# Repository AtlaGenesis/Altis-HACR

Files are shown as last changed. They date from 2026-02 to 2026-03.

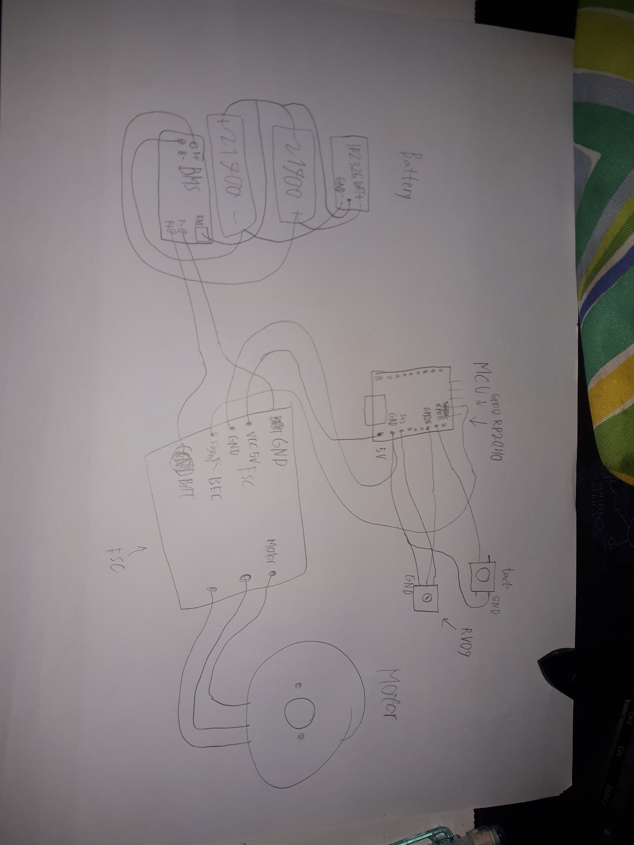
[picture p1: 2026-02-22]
Altis HACR/Wiring Diagram .jpg

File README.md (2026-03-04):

# Altis-HACR
A Handheld Fan designed for long and everlasting battery life, smooth airflow, and Compact Ergonomic design ready to accompany you in hot wheather.

# Elegant Design
Altis HACR
(rendered in fusion)
Gemini_Generated_Image_vhq5ehvhq5ehvhq5
(this one is AI-Generated only for visual effects, Don't use for ads)

# Usage instructions:
1. Position the fan so that you see the side with the fan blade furthest away from you.
2. Turn the knob all the way to the left
3. Press the button for 1 second
4. Slowly turn the knob to the right to adjust the wind speed, Hold the fan at 20-30cm distance from your face, to ensure air spreads across your face for maximum cooling and comfort
5. When you're done using, or that the device turned off, charge the device with a USB C cable, you can use your phone charger if it supports USB C
6. When it is charging, the LED indicator will turn red, when the battery is full, it will turn blue and will automatically stop charging

# Safety Features:
- It is designed with a shroud
- You can adjust the speed with a knob, allowing for smooth speed control suited for any situations
- It has an integrated battery protection system, preventing thermal runaways when an electrical error occured, and ensuring the batteries are not overcharged, and preventing the battery to reach 0% fully, as it can permanently damage the batteries
- Uses 2 Litium Ion batteries for higher energy density, safer discharge, and longer cycle life than Li-Po batteries
- The motor is a Brushless DC motor, allowing it to run faster, consumes lower power, and can operate comfortable for hours without overheating

# Wiring Diagram (sorry if paper)


# 3D printing material:

>ASA or stronger, Heated Bed, Enclosure, No Fan, Supports, Slow printing speed.
1. Body (Duct, Handle)
  - 25% Infill, Gyroid.
  - 6 - 8 Walls or Perimeter
  - White ASA
  - 0.12mm - 0.2mm Layer height, 0.4mm Nozzle
2. Fan Blade
  - 100% Infill
  - Walls or Perimeter set to MAX (MUST BE SOLID, 999 for most)
  - 0.12mm Layer Height, 0.4mm nozzle
  - Black ASA

>PETG, normal printing, little to no supports.
1. Fan Grill (PETG)
  - 100% Infill
  - Black PETG
  - 0.2mm / 0.4mm Layer height, 0.4mm Nozzle
  - 99 Walls or Perimeter
2. Knob (can be TPU)
  - 10% Infill
  - Black
  - 0.2mm-0.4mm Layer Height

# Why I made it
To be honest, it all started in 2025 of december when *I see these overpriced handheld fans on online shops, and wanted to compete with them*, then I bought a 15krpm rs280, and tested it with a toy fan blade, it was blowing my hair, so I thought: "why not make a cheaper one than theirs, but have better stuffs?"
and then I go to Blender and made it, I wasted my time, I discovered that DC motors sucks at long term use, so i abandoned the project, then I have an idea to make it using a PC axial fan, I did make it with my own money, I got discounted, I used it to chill in class, then I wanted to make a cleaner version, using those 100krpm edf turbo jet fan or something, those are inrunners, and... I figured out those aren't the best, cuz I know that it's impractical to have like 15 mins of runtime on 2 batteries..., so I made this! I calculated the rpm, tip speed, diameter, pitch, trying out fusion, trying out "parametric fan blade generator", then I dumped the generator, so I modified a pc fan blade design, and fit it into the motor (according to the motor desc), I made all of the stuffs (duct, handle, stator blades, etc) all without a reference, only a glimpse of what I imagined it would be like, so now I'm here, I really hope this would be my milestone in engineering, since I started making electronics in late october 2025, and I just discovered Hack Club back in December from an Instagram reel. 

# Special? 
I don't know, but after thinking for a while, I think it has some properties that are worth mentioning.
 1. Design
  The design is actually quite simple outside, but, it is not just a random duct, when you look closely into the cad, you'll see some hidden designs that you probably haven't seen before:
   

On the right side of the image, you can see a slight bell mouth shape inside, it's there to increase the air intake capability and also reducing turbulence, because the air can flow along the surfaces of the duct (That's why 0.12mm layer height is important!!!). And on the left side it's got a slight converging shape, to increase air velocity, and diverging to increase air spread, the small values of these shapes are choosen to maintain power efficiency and symmetry while also giving the effect it's intended to.



This picture shows the dimensions of the fan, these dimensions are calculated for maximum visual weight balance and comfort, 125mm long handle ensures it's not too long nor too short for your hand to grip, the fan diameter is chosen at 50mm for a balance of efficiency and portability, the 60mm duct diameter to 90mm centered duct lenght makes even better visual weight and symmetry, and the 2:1 handle to duct length and diameter also makes it perfectly balanced, for a very pleasing appearance.

# BOM
- 1x 1806 1700kv
https://shopee.co.id/Motor-Brushless-2s-3s-7.4V-12V-1806-1700KV-RC-Pesawat-i.165138131.40252534787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
- 
- 2x 21700 EVE 50E
https://shopee.co.id/Baterai-li-ion-3-7v-EVE-INR21700-50E-inr-21700-5000-mah-5-Ah-BARU-NEW-(5c-REAL-Grade-A-)-baterai-untuk-kendaraan-listrik-plts-alat-elektronik-la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
- 
- 1x BMS 2s 8A
https://shopee.co.id/BMS-2S-8A-8V-7.4V-8.4V-Baterai-Li-ion-Lithium-18650-Charger-Module-STANDAR-i.53753550.1999845549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
-
- 1x ESC BLHELI 12A BEC 5v 1A 2-3
https://shopee.co.id/BLHeli-12A-Mini-Brushless-Motor-ESC-BLHeli-14.2-2-3S-For-160-250-Multirotor-i.30918253.2840670835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
-
- 1x 10k potentiometer RV09 style
https://shopee.co.id/potensiometer-potentiometer-potensio-10k-rv09-12.5mm-RV-09-10-K-i.18663910.18844315772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
-
- 1x Tact switch 12x12x8mm
https://shopee.co.id/Tactile-Tact-Switch-Saklar-Push-On-Button-12*12mm-12x12mm-12x12-12*12-i.226801552.21733787099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
-
- 1x RP2040 Zero Raspberry Pi Pico
https://shopee.co.id/Raspberry-Pi-Pico-RP2040-Zero-Microcontroller-i.40647041.57550656215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
-
- 1x IP2326 2-3S charger module
https://shopee.co.id/IP2326-Step-Up-Battery-18650-Charger-Charging-2S-3S-BMS-With-Balance-1.5A-15Watt-Type-C-Battery-Charging-i.915347685.26127899926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
-
- 2x M2x8 screws rounded head
 https://shopee.co.id/Baut-JP-M2x8-Stainless-304-Phillips-Head-Screw-M2*8-Sekrup-2mm-x-8mm-M2-Obeng-Plus-SS304-i.96037146.24243396278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
-
- 2x M2x14 screws rounded head
 https://shopee.co.id/14mm-Baut-M2x14mm-M2-Phillips-Pan-Head-304-Stainless-Steel-i.76522437.25956472752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
-
- 6x M2x5 screws rounded head
https://shopee.co.id/Baut-JP-M2x5-Stainless-304-Phillips-Head-Screw-M2*5-Sekrup-2mm-x-5mm-M2-Obeng-Plus-SS304-i.96037146.27881616446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
-
- 8x M2x4x5 brass heat inserts
 https://shopee.co.id/Spiral-Brass-Nut-Insert-Spiral-brass-knur-insert-M2-M3-M4-(HARGA-PER-10PCS)-i.22308752.24463664962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

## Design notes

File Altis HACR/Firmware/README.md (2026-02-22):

# RP2040 ESC PWM Controller

## Wiring
- GIO12 → ESC signal
- GPIO15 → Button → GND
- GPIO26 → Pot wiper
- 3V3 → Pot
- GND → common ground

## Build
```bash
mkdir build
cd build
cmake ..
make

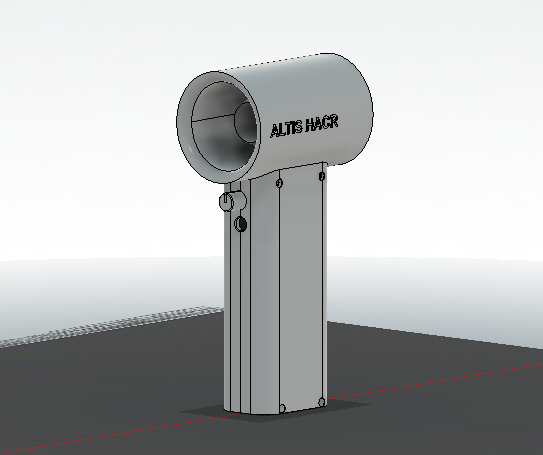
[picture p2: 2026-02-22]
Altis HACR/3D Models/View.png

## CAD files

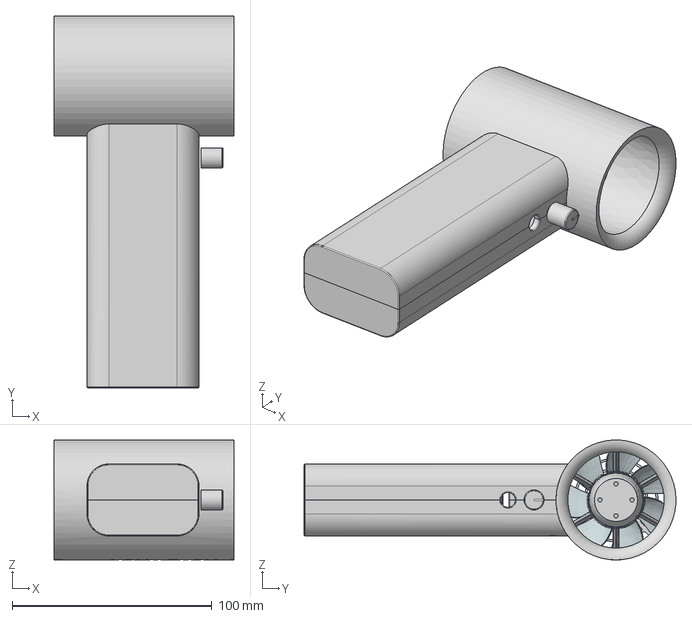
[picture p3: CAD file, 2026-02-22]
Altis HACR/3D Models/Altis HACR iterating.step
90.0 x 186.0 x 59.9 mm

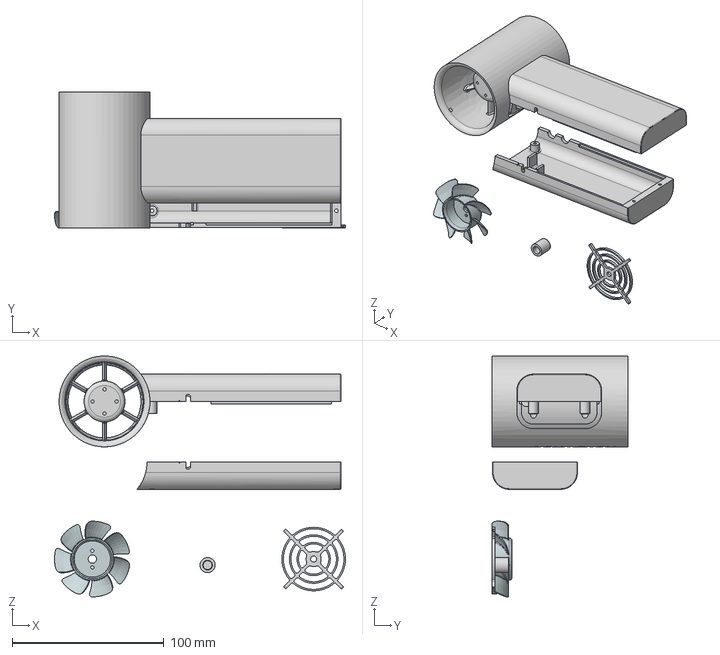
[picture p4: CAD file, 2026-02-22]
Altis HACR/3D Models/Altis HACR PRINT ONLY USING THIS PART!!!!.step
192.0 x 90.0 x 158.9 mm

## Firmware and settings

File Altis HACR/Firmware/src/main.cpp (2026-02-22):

#include "pico/stdlib.h"
#include "hardware/pwm.h"
#include "hardware/adc.h"
#include <algorithm>
#include <cstdlib>  // For std::abs (integers)

constexpr uint PWM_PIN = 16;
constexpr uint BUTTON_PIN = 15;
constexpr uint POT_ADC_INPUT = 0;
constexpr uint PWM_FREQ_HZ = 50;
constexpr uint16_t PWM_MIN_US = 1000;
constexpr uint16_t PWM_MAX_US = 2000;
constexpr uint32_t LONG_PRESS_MS = 1000;
constexpr uint32_t ESC_ARM_DELAY_MS = 2000;
constexpr uint16_t ADC_DEADBAND = 5;
constexpr uint32_t PWM_WRAP = 20000;  // 20ms period at 1MHz clock
constexpr uint16_t RAMP_STEP_US = 10; // Max adjustment per loop for safer ramping
constexpr uint32_t DEBOUNCE_MS = 10;  // Button debounce time

// Initializes PWM for 50Hz with 1us resolution.
// FIX: Return type changed from void to uint so pwm_slice can be returned.
uint init_pwm_50hz() {
    gpio_set_function(PWM_PIN, GPIO_FUNC_PWM);
    auto pwm_slice = pwm_gpio_to_slice_num(PWM_PIN);
    pwm_set_clkdiv(pwm_slice, 125.0f);  // Assumes 125MHz sys clock -> 1MHz PWM clock
    pwm_set_wrap(pwm_slice, PWM_WRAP);
    pwm_set_enabled(pwm_slice, true);
    return pwm_slice;
}

// Sets PWM duty cycle in microseconds, clamped to min/max.
void set_pwm_us(uint16_t us) {
    us = std::clamp(us, PWM_MIN_US, PWM_MAX_US);
    pwm_set_gpio_level(PWM_PIN, us);  // 1 tick = 1us
}

// Reads potentiometer via ADC and maps to PWM range (1000-2000us).
uint16_t read_pot_us() {
    uint16_t raw = adc_read();
    // Linear mapping: MIN + (raw / 4095.0) * (MAX - MIN), integer math for speed
    uint16_t mapped = PWM_MIN_US + (raw * (PWM_MAX_US - PWM_MIN_US)) / 4095;
    return std::clamp(mapped, PWM_MIN_US, PWM_MAX_US);
}

int main() {
    stdio_init_all();
    auto pwm_slice = init_pwm_50hz();  // Unused here, but available for expansion
    (void)pwm_slice;                   // Suppress unused variable warning

    gpio_init(BUTTON_PIN);
    gpio_set_dir(BUTTON_PIN, GPIO_IN);
    gpio_pull_down(BUTTON_PIN);  // Button to VCC; high when pressed

    adc_init();
    adc_gpio_init(26 + POT_ADC_INPUT);  // GPIO26 for ADC0
    adc_select_input(POT_ADC_INPUT);

    set_pwm_us(PWM_MIN_US);
    sleep_ms(ESC_ARM_DELAY_MS);  // Arm ESC by holding min PWM

    struct SystemState {
        bool is_on = false;
        bool is_pressed = false;
        bool last_btn = false;              // FIX: tracks last stable button state for debounce
        absolute_time_t press_start = nil_time;
        uint16_t current_pwm = PWM_MIN_US;
        absolute_time_t last_button_time = nil_time;
    } state;

    while (true) {
        bool current_btn = gpio_get(BUTTON_PIN);
        auto now = get_absolute_time();

        // FIX: Reset debounce timer on any state change, only act after stable for DEBOUNCE_MS
        if (current_btn != state.last_btn) {
            state.last_button_time = now;
            state.last_btn = current_btn;
        }

        if (absolute_time_diff_us(state.last_button_time, now) >= DEBOUNCE_MS * 1000) {
            // Rising edge (press)
            if (current_btn && !state.is_pressed) {
                state.is_pressed = true;
                state.press_start = now;
            }
            // Falling edge (release)
            if (!current_btn && state.is_pressed) {
                state.is_pressed = false;
                uint32_t held_ms = static_cast<uint32_t>(
                    absolute_time_diff_us(state.press_start, now) / 1000);
                if (held_ms >= LONG_PRESS_MS) {
                    state.is_on = !state.is_on;
                }
            }
        }

        // PWM control: Ramp towards target with deadband and step limit
        if (state.is_on) {
            uint16_t target = read_pot_us();
            int16_t diff = static_cast<int16_t>(target) - static_cast<int16_t>(state.current_pwm);
            if (std::abs(diff) > ADC_DEADBAND) {
                uint16_t step = std::min(static_cast<uint16_t>(std::abs(diff)), RAMP_STEP_US);
                state.current_pwm += (diff > 0) ? step : -step;
                set_pwm_us(state.current_pwm);
            }
        } else {
            state.current_pwm = PWM_MIN_US;
            set_pwm_us(PWM_MIN_US);
        }

        sleep_ms(1);  // ~1kHz loop rate
    }
}

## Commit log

2026-01-29 adds RGB 3mm LED from the parts list
2026-01-31 Enhance README with design and printing details
    Added sections for elegant design and 3D printing material specifications.
2026-01-31 Update quantity of brass heat inserts in README
    is required to improve grip on structures
2026-02-01 Update README with usage and safety information
    Added usage instructions and safety features for the device.
2026-02-02 Update BOM with purchase links for components
    Added links to purchase components in the BOM section.
2026-02-22 I Iterated the 3D model to be stronger
    I had low experience in Fusion 360 when I first make this, so I made other projects to increase my experience and then improving this project before finalizing it
    [Altis HACR PRINT ONLY USING THIS PART!!!!.step, Altis HACR iterating.step, BILLINGS OF MATERIALS.csv]
2026-02-22 Revise 3D printing specifications
    Updated 3D printing material specifications for various components, including body, fan blade, and fan grill. Revised infill percentages, layer heights, and material types for improved clarity and pr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
2026-02-23 Enhance README with usage details and design insights
    Updated usage instructions for better clarity and added details about fan design properties.
2026-03-04 Revise 3D printing material settings
    Updated 3D printing material recommendations for improved results.
